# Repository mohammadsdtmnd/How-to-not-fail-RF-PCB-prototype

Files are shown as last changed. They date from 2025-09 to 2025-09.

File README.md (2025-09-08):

# How to not fail RF PCB prototype
I've made GPS amplifier for hobby time, it failed. I've learned what I should not have done again to prevent failure. My motivation for doing this was to see the GPS signal spectrum. :) Note I had tried my best to minimize cost. For example by eliminating stensil and soldermask. Though still PCB is metalized with bot layer gnd. I think I could also not making it metalized. Making it stiching with thin wire, instead. Since metalizing caused my manufacturer to prolong a long time.

**You can look at schematic and PCB and see these strength:**

+ Simple
+ High gain
+ Extremely compact design
+ 0.25mm PCB thickness chosen to decrease track and match them to RF amps
+ small footprint which also causes them to be more stable because of less leakage

This compact design chosen to minimize distortion in GPS RF signal.

**PCB Weakness:**
  
+ 0.5mm pitch footprint is small for handsoldering
+ Amplifier package does not have edge lead tail, to make you certain about solder connectivity

But other than foot print and devices package chosen, tools are extremely important:

**Tools weakness:**
  
+ Bulky 60W iron used and caused catastrophy there :(
+ Use of thick solder wire
+ Lower melting point solder plus hot air could help success of assmbling but was missed

**Tools strength:**
  
+ Precise tweezer
+ Good lenz for zooming

And the thing I had really missed was to be patience to waint until accessing at least SMD specialized iron.

**Here is manufactured PCB:**




**Prepaird workbench:**



**First try success:**



**but the secound not:**



I had placed tip of my bulky iron beneath the IC and the resin of PCB burnd!! Though I've been dissapointed. I told OK. I will make the secound PCB with success.
The secound PCB had inherent wrong. It missed one track in sensitive area, Under amplifier. :(


But I managed to handle it with 0.1mm Wire, Low melting solder and Hot air




**And the result was promising:**



Though I've assembled all amplifier with success. Then I tried to place other components with my bulky iron and wire solder. Then another tack removed and caused to one amplifier being detached.


Now next time I will be sure to use smd iron.
Then all components should have more than 1mm pitch for handsoldering. Otherwise I should have sharp tip iron with low melting point solder if possible. Plus patience.

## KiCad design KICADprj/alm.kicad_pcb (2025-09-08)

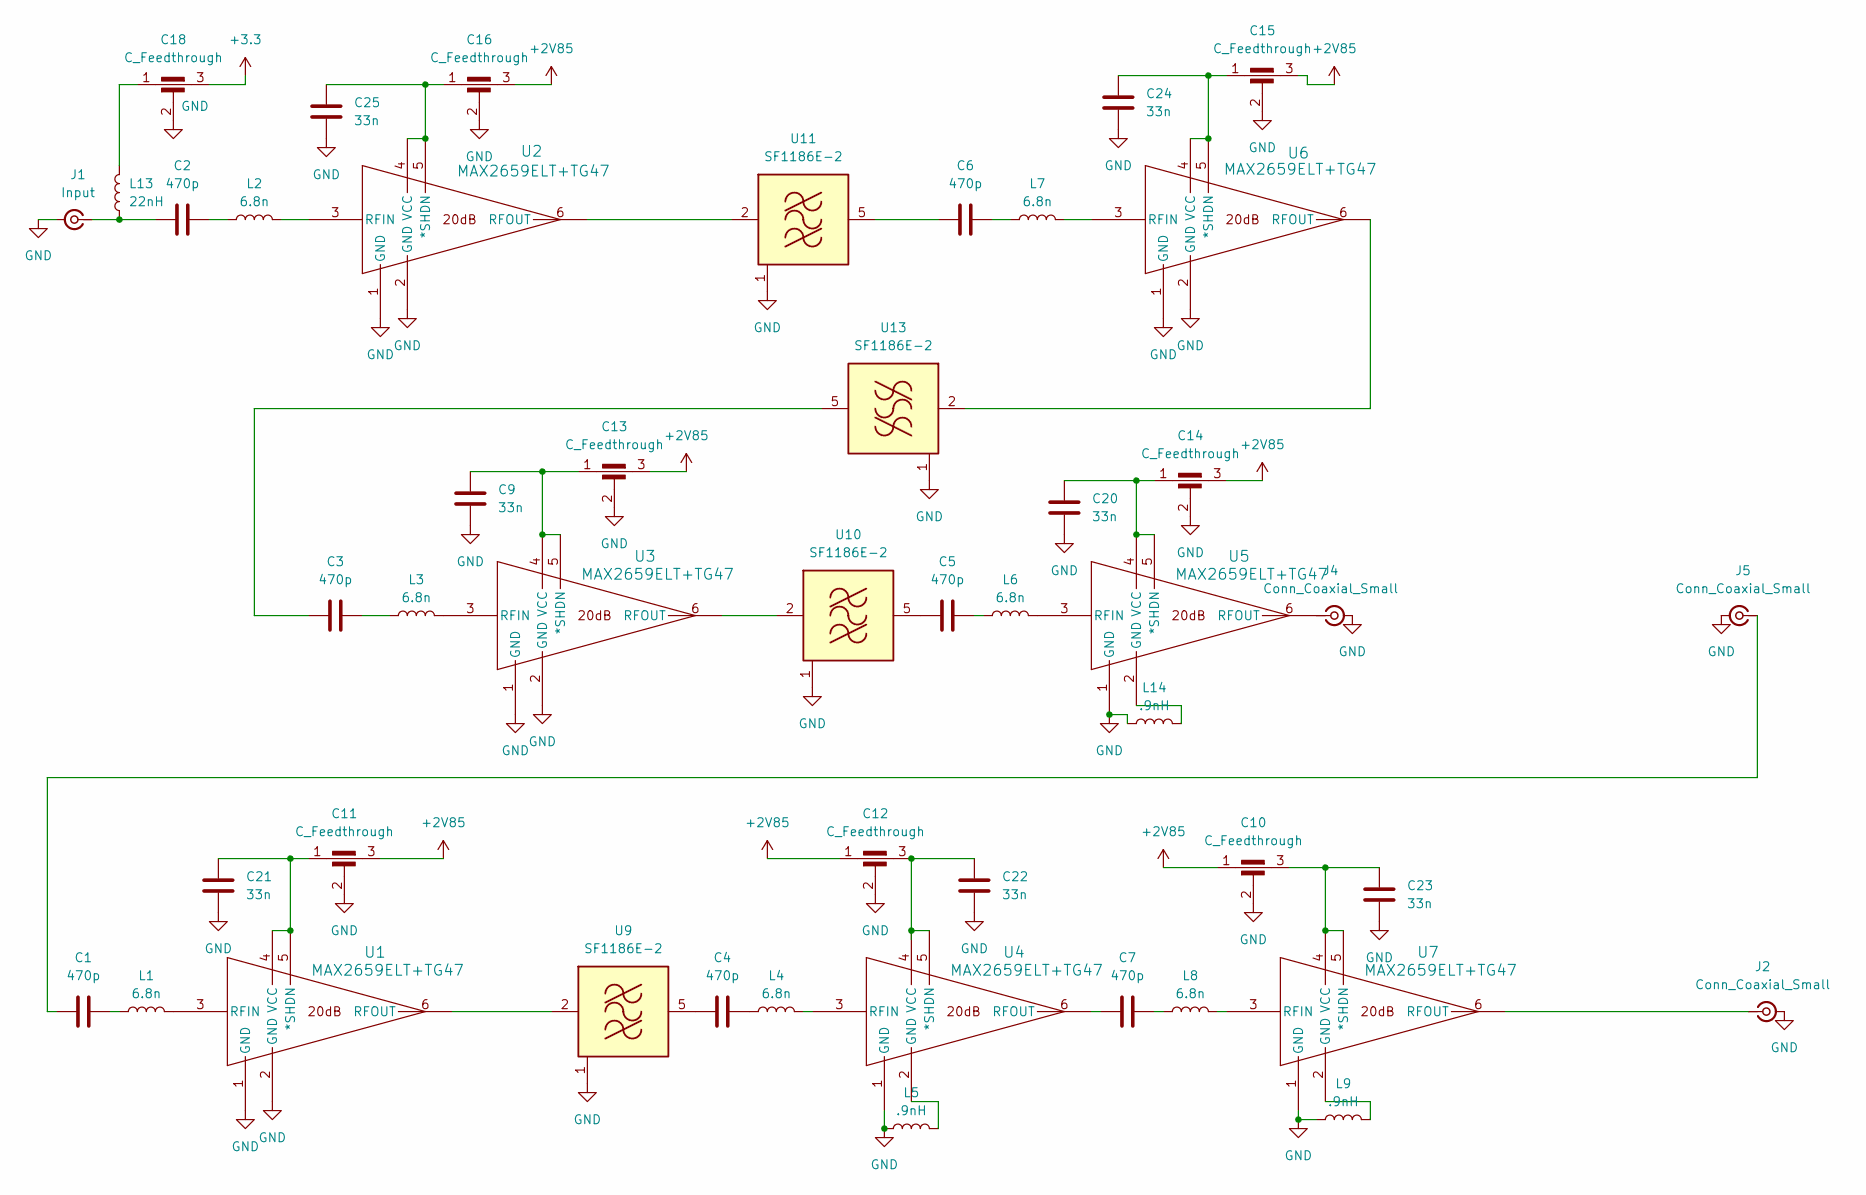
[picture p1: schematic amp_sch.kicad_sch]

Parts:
C1, C2, C3, C4, C5, C6, C7: 470p; C_0402_1005Metric_Pad0.74x0.62mm_HandSolder
C9, C20, C21, C22, C23, C24, C25: 33n; C_0402_1005Metric_Pad0.74x0.62mm_HandSolder
C10, C11, C12, C13, C14, C15, C16, C18: C_Feedthrough; FeedThrough_NFM3DPC
J1: Input; SMA_Molex_73251-1153_EdgeMount_Horizontal
J2, J4, J5: Conn_Coaxial_Small; SMA_Molex_73251-1153_EdgeMount_Horizontal
L1, L2, L3, L4, L6, L7, L8: 6.8n; L_0402_1005Metric_Pad0.77x0.64mm_HandSolder
L5, L9, L14: .9nH; L_0402_1005Metric
L13: 22nH; L_0603_1608Metric
U1, U2, U3, U4, U5, U6, U7: MAX2659ELT+TG47; UDFN-6 1.5x1x.75mm
U9, U10, U11, U13: SF1186E-2; Filter_SAW_Epcos_DCC6C_3x3mm

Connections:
+2V85: C10.1, C11.3, C12.1, C13.3, C14.3, C15.3, C16.3; also elsewhere on the board
+3.3: C18.3; also elsewhere on the board
GND: C9.1, C10.2, C11.2, C12.2, C13.2, C14.2, C15.2, C16.2, C18.2, C20.1, C21.1, C22.1, C23.1, C24.1, C25.1, J1.2 (Ext), J2.2 (Ext), J4.2 (Ext), J5.2 (Ext), L5.1, L9.1, L14.1, U1.1 (GND), U1.2 (GND), U2.1 (GND), U2.2 (GND), U3.1 (GND), U3.2 (GND), U4.1 (GND), U5.1 (GND), U6.1 (GND), U6.2 (GND), U7.1 (GND), U9.1 (GND), U9.3 (GND), U9.4 (GND), U9.6 (GND), U10.1 (GND), U10.3 (GND), U10.4 (GND), U10.6 (GND), U11.1 (GND), U11.3 (GND), U11.4 (GND), U11.6 (GND), U13.1 (GND), U13.3 (GND), U13.4 (GND), U13.6 (GND); also elsewhere on the board
unnamed: C1.2, L1.1
unnamed: C2.2, L2.1
unnamed: C3.2, L3.1
unnamed: C4.2, L4.1
unnamed: C5.2, L6.1
unnamed: C6.2, L7.1
unnamed: C7.2, L8.1
unnamed: C18.1, L13.2
unnamed: C2.1, J1.1 (In), L13.1
unnamed: J2.1 (In), U7.6 (RFOUT)
unnamed: J4.1 (In), U5.6 (RFOUT)
unnamed: C1.1, J5.1 (In)
unnamed: L5.2, U4.2 (GND)
unnamed: L9.2, U7.2 (GND)
unnamed: L14.2, U5.2 (GND)
unnamed: C11.1, C21.2, U1.4 (VCC), U1.5 (*SHDN)
unnamed: L1.2, U1.3 (RFIN)
unnamed: U1.6 (RFOUT), U9.2 (IN)
unnamed: C16.1, C25.2, U2.4 (VCC), U2.5 (*SHDN)
unnamed: L2.2, U2.3 (RFIN)
unnamed: C9.2, C13.1, U3.4 (VCC), U3.5 (*SHDN)
unnamed: L3.2, U3.3 (RFIN)
unnamed: C12.3, C22.2, U4.4 (VCC), U4.5 (*SHDN)
unnamed: L4.2, U4.3 (RFIN)
unnamed: C7.1, U4.6 (RFOUT)
unnamed: C14.1, C20.2, U5.4 (VCC), U5.5 (*SHDN)
unnamed: L6.2, U5.3 (RFIN)
unnamed: C15.1, C24.2, U6.4 (VCC), U6.5 (*SHDN)
unnamed: L7.2, U6.3 (RFIN)
unnamed: C10.3, C23.2, U7.4 (VCC), U7.5 (*SHDN)
unnamed: L8.2, U7.3 (RFIN)
unnamed: C4.1, U9.5 (OUT)
unnamed: U3.6 (RFOUT), U10.2 (IN)
unnamed: C5.1, U10.5 (OUT)
unnamed: U2.6 (RFOUT), U11.2 (IN)
unnamed: C6.1, U11.5 (OUT)
unnamed: U6.6 (RFOUT), U13.2 (IN)
unnamed: C3.1, U13.5 (OUT)

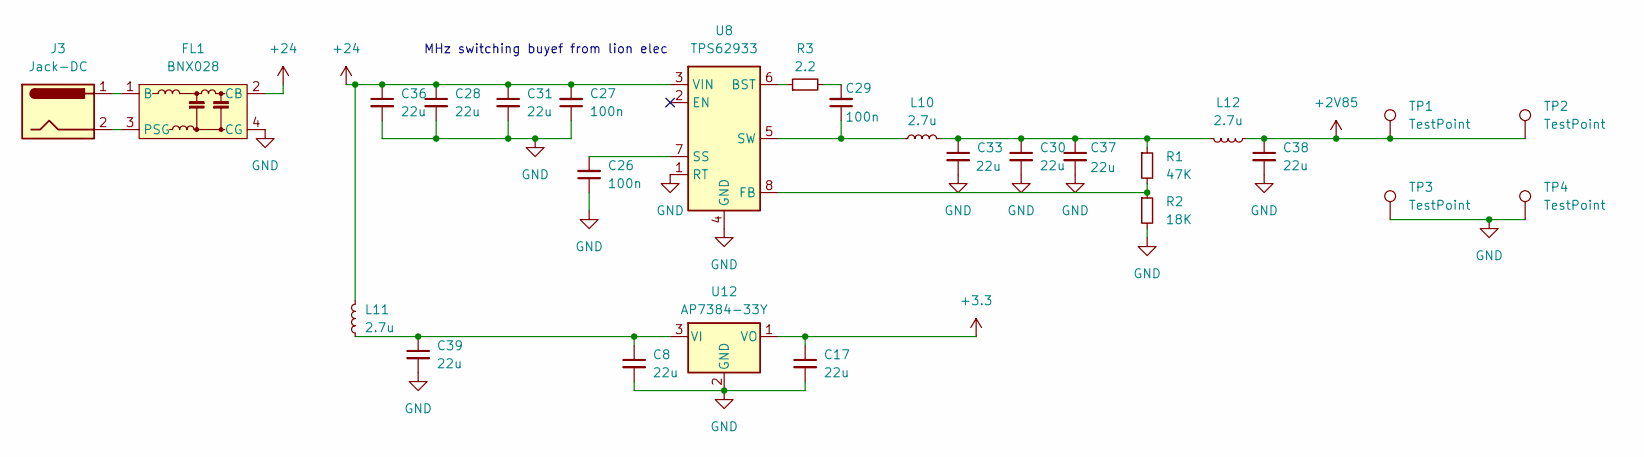
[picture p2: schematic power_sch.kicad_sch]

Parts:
C8, C17, C28, C30, C31, C33, C36, C37, C38, C39: 22u; C_0805_2012Metric
C26, C27, C29: 100n; C_0402_1005Metric_Pad0.74x0.62mm_HandSolder
FL1: BNX028; Filter_Murata_BNX025
J3: Jack-DC; BarrelJack_Horizontal
L10, L11, L12: 2.7u; 4x4x2.8mmIND_VLCF4028T-2R7N1R8-2
R1: 47K; R_0402_1005Metric
R2: 18K; R_0402_1005Metric
R3: 2.2; R_0402_1005Metric
TP1, TP2, TP3, TP4: TestPoint; SolderWirePad_1x01_SMD_5x10mm
U8: TPS62933; SOT-583-8
U12: AP7384-33Y; SOT-89-3

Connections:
+2V85: C38.1, L12.1, TP1.1, TP2.1; also elsewhere on the board
+3.3: C17.1, U12.1 (VO); also elsewhere on the board
+24: C27.2, C28.1, C31.1, C36.1, FL1.2 (CB), L11.2, U8.3 (VIN)
GND: C8.2, C17.2, C26.1, C27.1, C28.2, C30.2, C31.2, C33.2, C36.2, C37.2, C38.2, C39.2, FL1.4 (CG), R2.2, TP3.1, TP4.1, U8.1 (RT), U8.4 (GND), U12.2 (GND); also elsewhere on the board
unnamed: C29.2, R3.2
unnamed: C30.1, C33.1, C37.1, L10.2, L12.2, R1.1
unnamed: FL1.1 (B), J3.1
unnamed: FL1.3 (PSG), J3.2
unnamed: R3.1, U8.6 (BST)
unnamed: R1.2, R2.1, U8.8 (FB)
unnamed: C26.2, U8.7 (SS)
unnamed: C29.1, L10.1, U8.5 (SW)
unnamed: C8.1, C39.1, L11.1, U12.3 (VI)

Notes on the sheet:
MHz switching buyef from lion elec

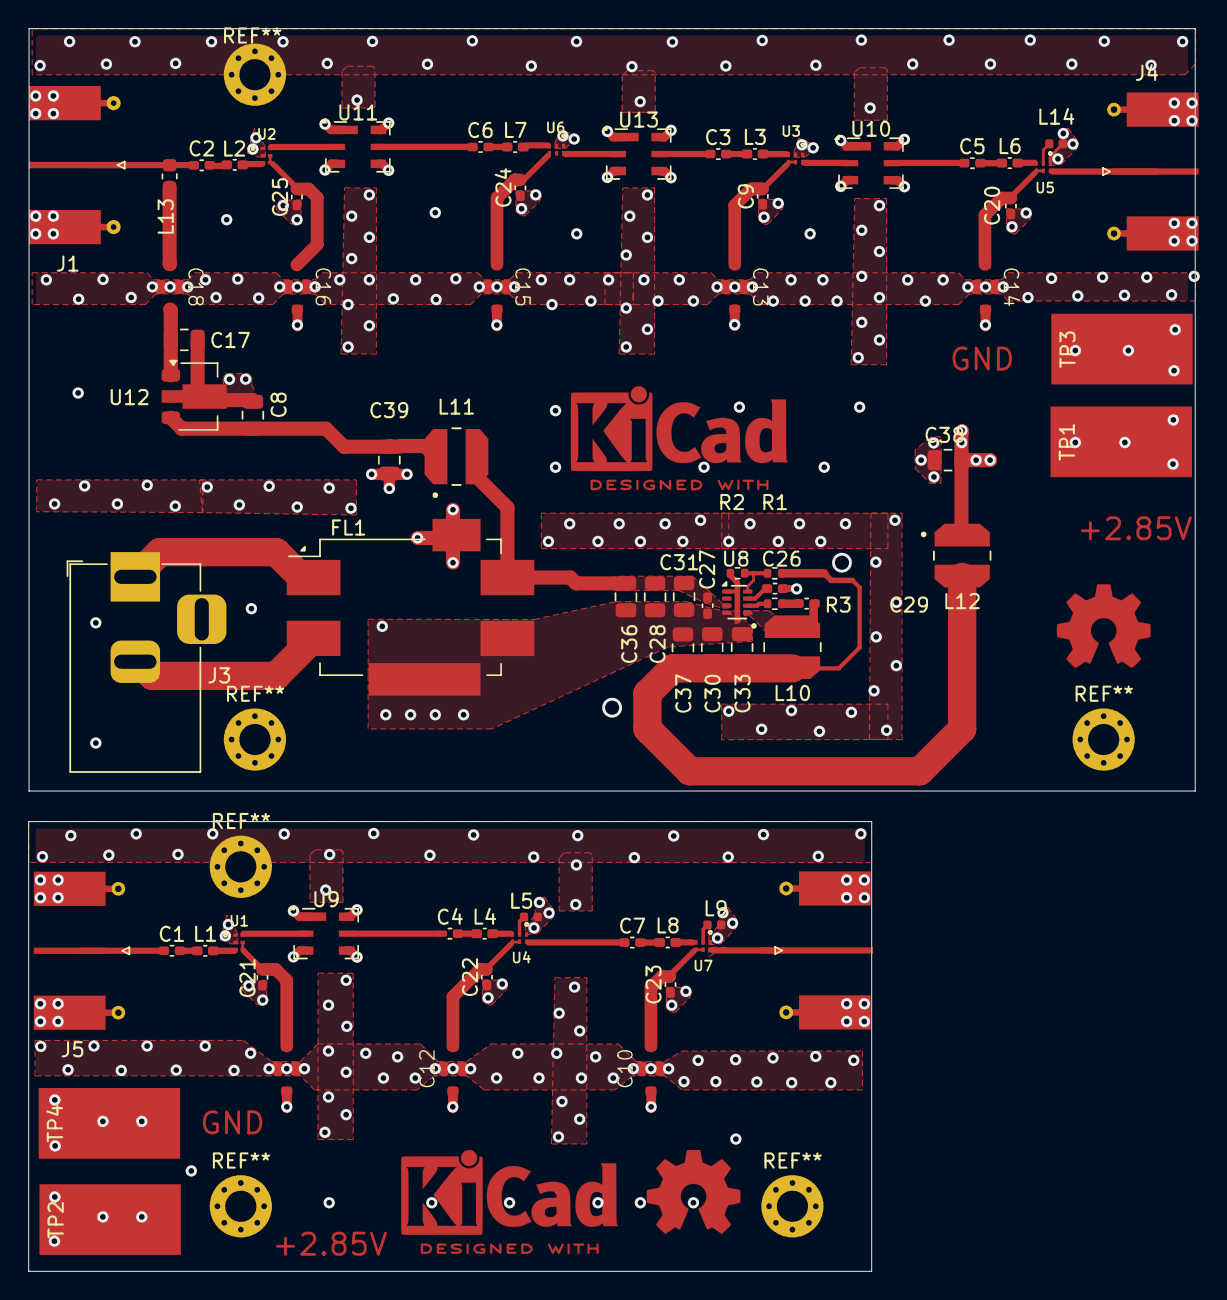
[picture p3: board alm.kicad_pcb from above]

Board: 4 copper layers, 82.5 x 87.9 mm, 75 parts (0 on the bottom side), 51 nets.

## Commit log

2025-09-08 Update README.md
    More data about PCB layer and its fab options added in top paragraph.
2025-09-08 Create KiCadProj
    Kicad project files here
2025-09-08 Delete KiCadProj
    Deleted redundant files
2025-09-08 added project
    [alm.kicad_pcb, alm.kicad_sch, amp_sch.kicad_sch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]
